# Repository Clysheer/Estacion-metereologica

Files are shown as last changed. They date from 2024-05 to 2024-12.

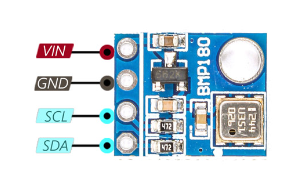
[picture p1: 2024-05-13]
PCB/Documentacion/Pin-out-BMP80.png

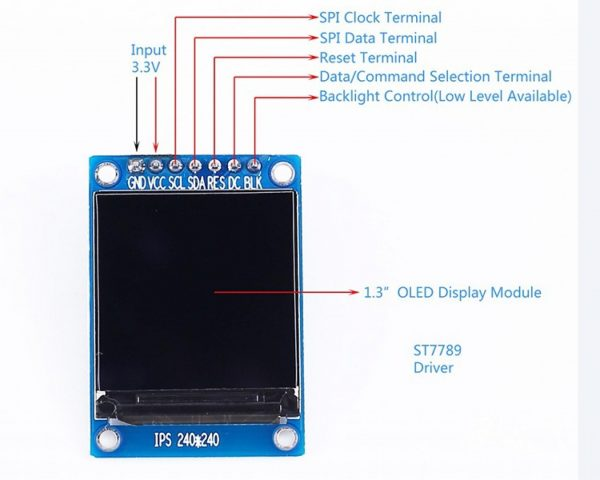
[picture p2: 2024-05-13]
PCB/Documentacion/Pin-ot-st7789.png

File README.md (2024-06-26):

# Estacion-metereologica
La  Estación  Meteorológica  es  un  dispositivo  que  tiene  la  capacidad  de  medir  la temperatura  ambiente,  humedad  y  presión  atmosférica  del  lugar  específico  en  el  que  se encuentre  el  dispositivo  y  también  puede  visualizar  la  temperatura  de  una  zona geográfica  predeterminada  (ej:  Lomas  de  Zamora).  Todo  esto  utilizando  la  pantalla ST7789 de 240*240 pixeles que al ser oled mostrará al usuario los datos extraídos de manera fácil y sencilla. Todo esto utilizando como cerebro al microcontrolador ESP32que  utilizando  su  conexión  Wifi  logre  interactuar  con  la  utilización  de  una  API,  la  cual recibirá  los  datos  de  la  zona  geográfica  y  los  mostrará  por  la  pantalla,  y  además, utilizando  los  sensores  de  Presión  Atmosférica  BPM  180  y  el    DHT11  de  temperatura  y humedad  calcule  la  temperatura  del  ambiente  y  la  presión  atmosférica.
En  definitiva,  es  un  dispositivo  compuesto  por  un  microcontrolador  ESP32,  una  pantalla oled  y  unos  sensores  de  temperatura,  humedad  y  presión  atmosférica.
Al  tamaño  de  la  pantalla  ser  relativamente  pequeña,  los  datos  extraídos  del  sensor DHT11  y  de  la  API  se  irán  mostrando  por  la  pantalla  ST7789  en  manera  de  turnos, cada  15  segundo  pasará  de  mostrar  la  temperatura  ambiente  a  mostrar  la  meteorología de manera ciclica, así el usuario puede recibir ambas informaciones sin la necesidad de la utilizacion de un boton.
Todo esto será alimentado sin la utilización de baterías, si no que será alimentado mediante un cargador de 240v con una salida de 5v (cargador de celular) que ira conectado a la placa del dispositivo.
El  proyecto  está  planteado  como  un  proyecto  de  inicio,  el  costo  económico  no  es  muy alto  y  sirve  como  inicio  a  la  utilización  del  microcontrolador  ESP32  y  su  conectividad wifi.



*Diagrama  en  bloques:*



*Materiales :*

1-Pantalla DISPLAY TFT ST7789  240*240

2-ESP  WROOM  32  DEVKIT  V1

3-DHT11 Sensor Temperatura 

4-Placa  PCB  Simple  Faz  10x10

5-Sensor Presion Atmosferica Bmp180

*Diseño 3D :*







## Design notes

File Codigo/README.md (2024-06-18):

Esta carpeta contiene todos los codigos utilizados para la creacion de la 
Estacion Meteorologica Soulka, Incluye el codigo base y los distintos codigos 
utilizados para los sensores dht11 y bmp180, pantalla st7789 y conexion Wifi.

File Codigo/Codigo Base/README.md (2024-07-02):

Codigo que se encuentra subido al esp32 utilizado por la Estacion Meteorologica

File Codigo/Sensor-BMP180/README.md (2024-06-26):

El sensor BMP180 es un sensor de presión atmosférica y temperatura barométrico de alta precisión fabricado por Bosch.                        puede proporcionar datos de temperatura, presión atmosférica y altitud.                                                                      
                                                                                                                                             El sensor de presión barométrica BMP180 está diseñado para leer la presión atmosférica y de esta forma estimar indirectamente la Altura sobre el nivel del mar. La presión atmosférica es la fuerza que ejerce el aire (atmósfera) sobre la superficie de la tierra. La presión atmosférica se debe al peso de la columna de aire sobre determinada área, es por esta razón que al medir la presión atmosférica en puntos con mayor altitud, el valor de la presión es menor por ser menor la cantidad de aire. La presión atmosférica también varía con el clima, principalmente con la temperatura, pues esta hace cambiar la densidad del aire, que se ve reflejado en un cambio en el peso y por consiguiente en un cambio de presión.                                                                                                                                                                                                                                                                                                                                                                                  Características Técnicas                                                                                                                                                                                                                                                             
Mediciones:                                                                                                                              
Presión atmosférica absoluta                                                                                                              
Temperatura ambiente.                                                                                                                                                                                                                                        
Precisión:                                                                                                                                
Presión:                                                                                                                                  
   Rango: 300 hPa a 1100 hPa.                                                                                                              
   Resolución: 0.01 hPa.                                                                                                                      
   Precisión: ±1 hPa.                                                                                                                      
Temperatura:  
  Rango: -40°C a +85°C.                                                                                                                      
  Resolución: 0.1°C.                                                                                                                                              
  Precisión: ±2°C.                                                                                                                                    
Voltaje de Operación: 1.8V a 3.6V (generalmente se usa con 3.3V o 5V).                                                                                  
Interfaz de Comunicación: Utiliza el protocolo I2C para la comunicación con microcontroladores.                                                                                                                                                                                                                                          
El sensor BMP180 tiene cuatro pines:

VCC: Alimentación (3.3V a 5V).                                                                                                                    
GND: Conexión a tierra.                                                                                                                                        
SCL: Línea de reloj del bus I2C.                                                                                                                          
SDA: Línea de datos del bus I2C.

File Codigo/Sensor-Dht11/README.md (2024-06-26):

El sensor DHT11 es un sensor utilizado para la medicion de temperatura y humedad,
a diferencia de otro sensores medidores de temperatura y humedad este presume de ser un sensor con una alta fiabilidad y estabilidad debido a su señal digital calibrada.

Caracteristicas Tecnicas:

Mediciones: Proporciona lecturas de temperatura y humedad relativa.                                                                          
Precisión:                                                                                                                                   
  Temperatura: ±2°C                                                                                                                            Humedad: ±5% RH                                                                                                                            Rango de Medición:                                                                                                                        
Temperatura: 0°C a 50°C
Humedad: 20% a 90% RH                                                                                                                       
Voltaje de Operación: 3.3V a 5V (generalmente se recomienda 5V para asegurar una operación estable)                                         
Interfaz de Comunicación: Utiliza un solo bus de datos para la lectura de los sensores de temperatura y humedad.                            
Tiempo de Respuesta: Lecturas de temperatura cada 2 segundos, y de humedad cada 2 segundos.

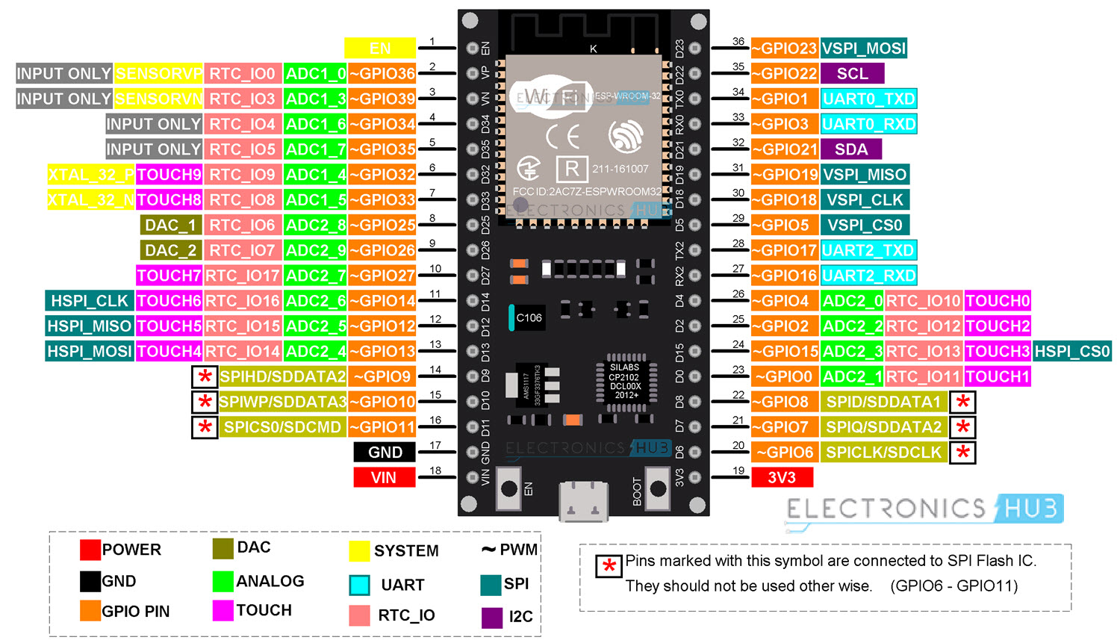
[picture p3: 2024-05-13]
PCB/Documentacion/Pin-out-Esp32.png

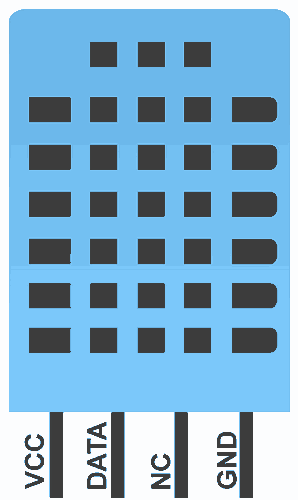
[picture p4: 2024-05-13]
PCB/Documentacion/Pin-out-DHT11.png

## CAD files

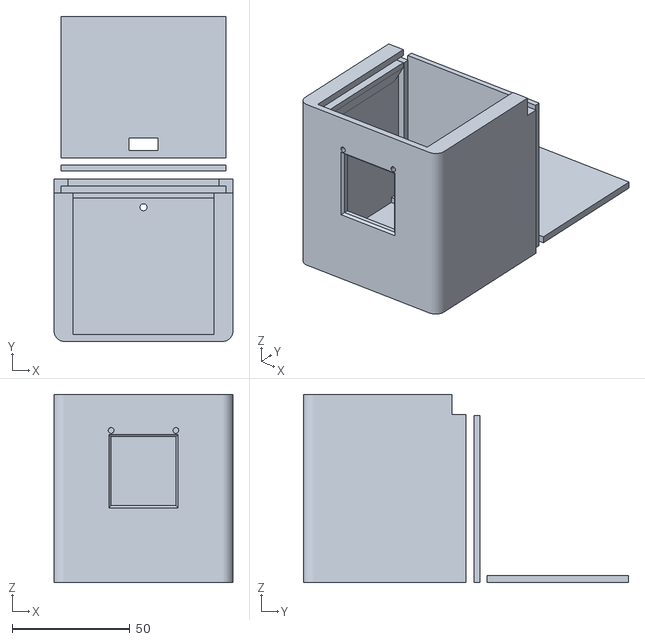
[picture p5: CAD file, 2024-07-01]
DISEÑO 3D/Estacion Meteorologica v6.stl
76.0 x 138.0 x 80.0

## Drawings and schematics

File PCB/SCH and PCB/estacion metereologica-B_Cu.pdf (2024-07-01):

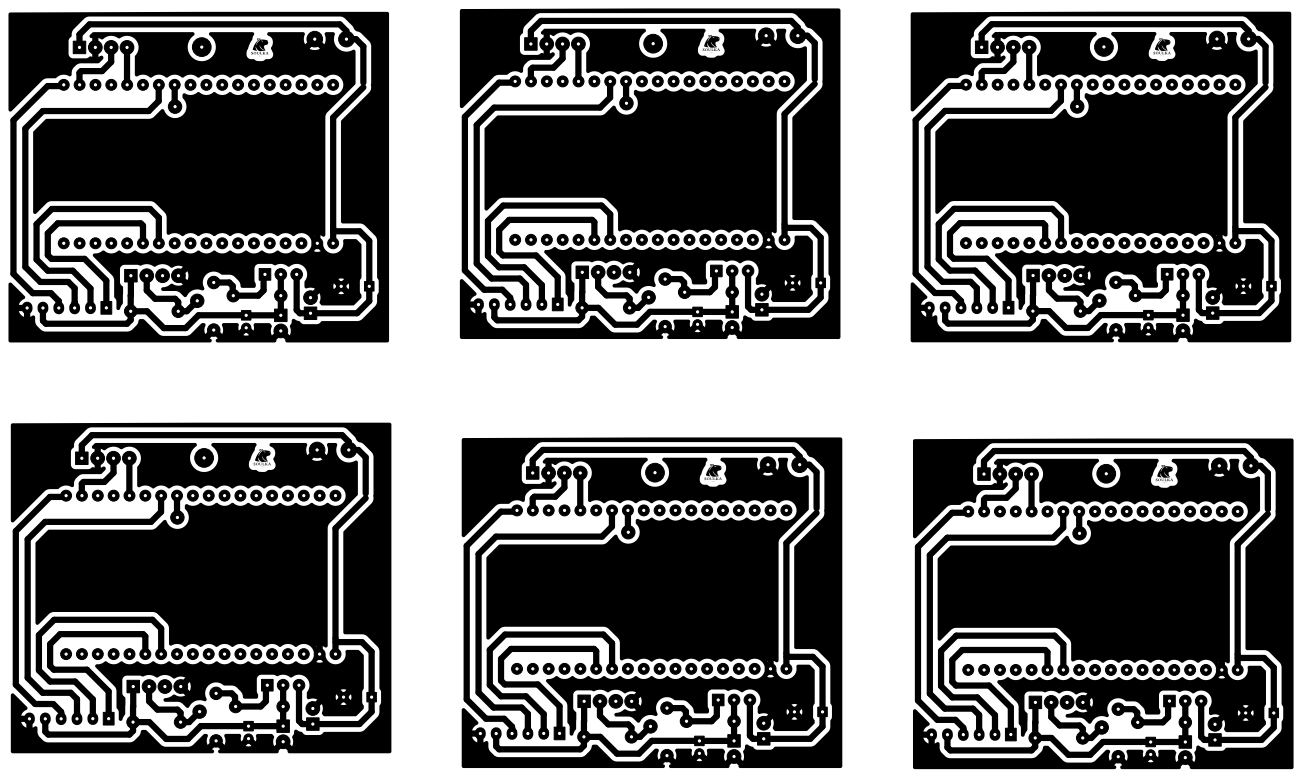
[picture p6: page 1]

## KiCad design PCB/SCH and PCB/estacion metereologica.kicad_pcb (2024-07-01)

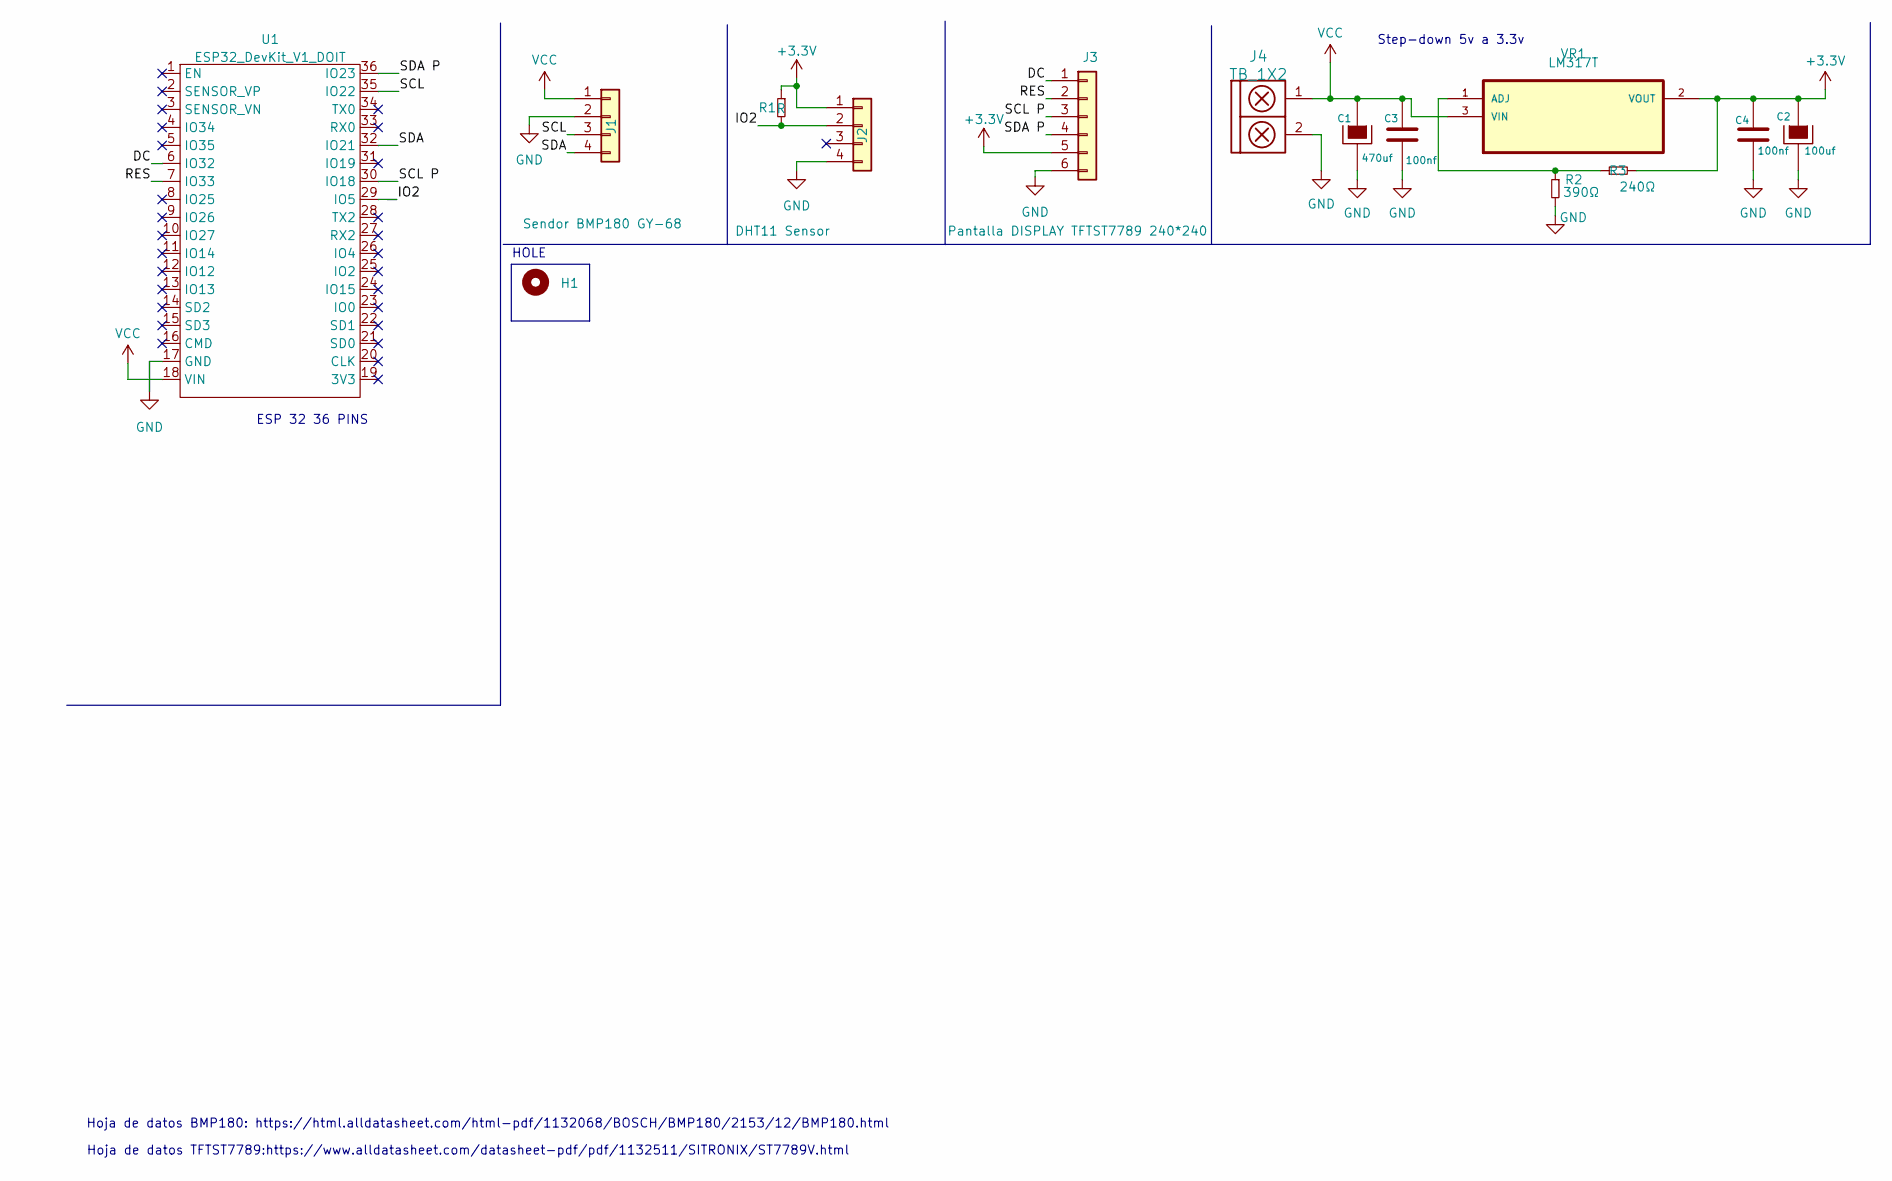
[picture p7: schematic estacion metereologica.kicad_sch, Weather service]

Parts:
C1: 470uf; CAP_ELEC_10X8mm
C2: 100uf; CAP_ELEC_5x11mm
C3, C4: 100nf; CP_Radial_Tantal_D4.5mm_P2.50mm
H1: Mounting_Hole; Tornillo_M3_8mm
J1: Sendor BMP180 GY-68; FanPinHeader_1x04_P2.54mm_Vertical
J2: DHT11 Sensor; FanPinHeader_1x04_P2.54mm_Vertical
J3: Pantalla DISPLAY TFTST7789 240*240; FanPinHeads_1x6_P2.54mm_Vertical
J4: TB_1X2; BORNERA2_AZUL
R1: R; RES0.3
R2: 390Ω; RES0.3
R3: 240Ω; RES0.3
U1: ESP32_DevKit_V1_DOIT; ESP32_DEVKIT_V1_DOIT
VR1: LM317T; TO254P1054X470X1955-3

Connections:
+3.3V: C2.1, C4.1, J2.1, J3.5, R1.1, R3.2, VR1.2 (VOUT)
/DC: J3.1, U1.6 (IO32)
/IO2: J2.2, R1.2, U1.29 (IO5)
/RES: J3.2, U1.7 (IO33)
/SCL: J1.3, U1.35 (IO22)
/SCL P: J3.3, U1.30 (IO18)
/SDA: J1.4, U1.32 (IO21)
/SDA P: J3.4, U1.36 (IO23)
GND: C1.2, C2.2, C3.2, C4.2, J1.2, J2.4, J3.6, J4.2, R2.2, U1.17 (GND)
unnamed: R2.1, R3.1, VR1.1 (ADJ)
VCC: C1.1, C3.1, J1.1, J4.1, U1.18 (VIN), VR1.3 (VIN)

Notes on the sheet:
Hoja de datos TFTST7789:https://www.alldatasheet.com/datasheet-pdf/pdf/1132511/SITRONIX/ST7789V.html
Step-down 5v a 3.3v
HOLE
Hoja de datos BMP180: https://html.alldatasheet.com/html-pdf/1132068/BOSCH/BMP180/2153/12/BMP180.html
ESP 32 36 PINS

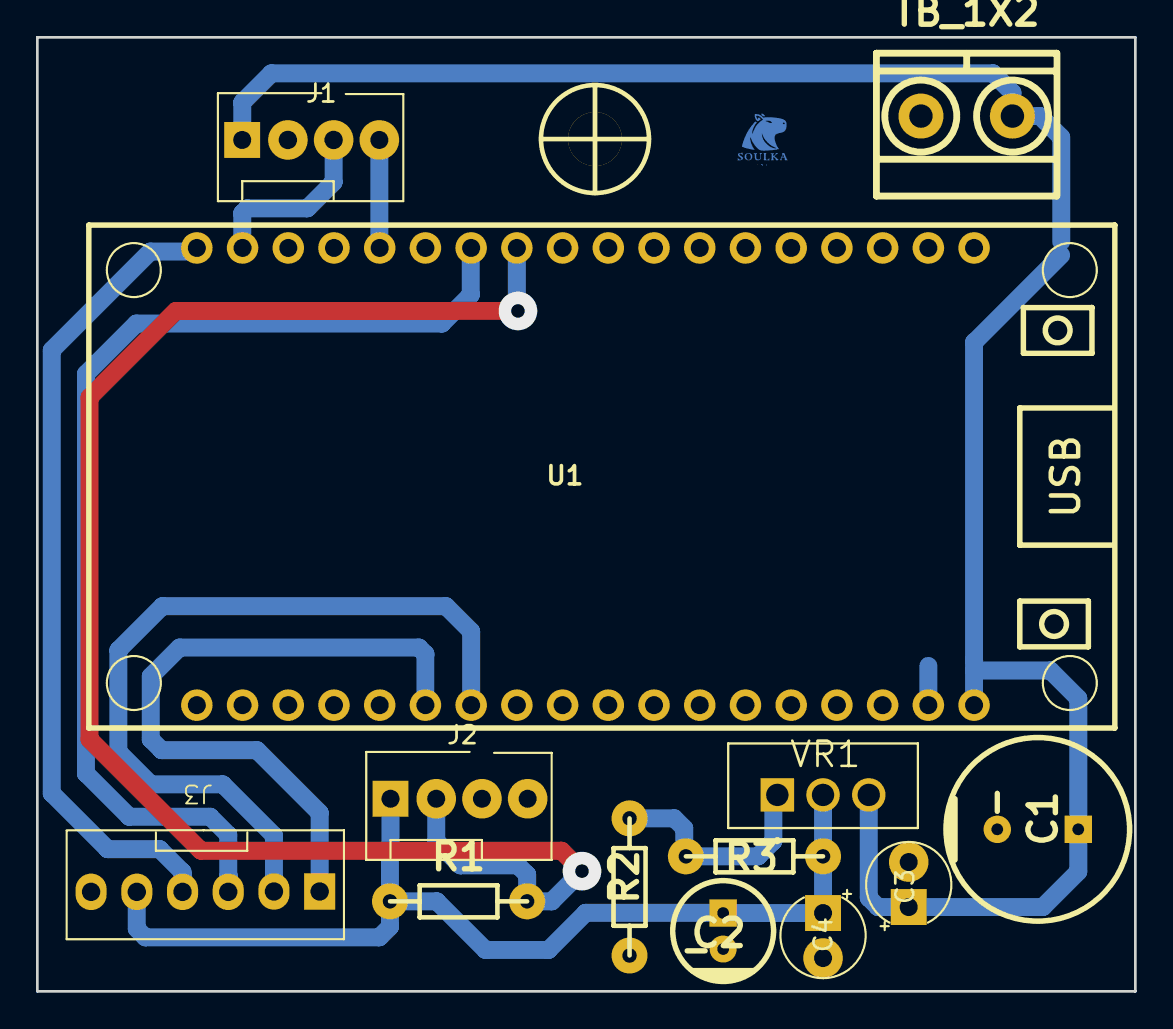
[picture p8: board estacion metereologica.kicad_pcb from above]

Board: 2 copper layers, 61.0 x 53.0 mm, 14 parts (0 on the bottom side), 11 nets.

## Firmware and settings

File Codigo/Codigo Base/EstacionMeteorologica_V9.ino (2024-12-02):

#include <WiFi.h>
#include <HTTPClient.h>
#include <ArduinoJson.h>
#include <TFT_eSPI.h>
#include <SPI.h>
#include <DHT.h>
#include <DHT_U.h>
#include <Adafruit_BMP085.h>

#define PIN_DHT 5
#define DHTTYPE DHT11
#define PRUEBA 1
DHT dht(PIN_DHT, DHTTYPE);
TFT_eSPI tft = TFT_eSPI();
Adafruit_BMP085 bmp;

//Redes wifi
//const char* ssid = "Taller_Electronica_5GHz";       
//const char* password = "robotica";
//const char* ssid = "Maestros";
//const char* password = "Maestros_2021";
const char* ssid = "Estudiantes";       
const char* password = "educar_2018";
//const char* ssid = "Vllamada";       
//const char* password = "Vllamada_2021";

String URL = "http://api.openweathermap.org/data/2.5/weather?"; // URL para la API
String ApiKey = "44d3a7d9ae8f99c1cdc98166cf3bb5f8";             //Clave de la URL

// Ubicacion de los parametros meteorologicos
String lat = "Temperley";               
String lon = "Argentina";


unsigned long tiempoAnterior = 0;  // Almacena el tiempo anterior
const long intervalo = 10000;  // Intervalo de 10 segundos (en milisegundos)

int estado = 0;  // Estado para alternar entre las dos frases

void setup() {
  Serial.begin(9600);
  WiFi.begin(ssid, password);
  tft.init();
  tft.fillScreen(TFT_BLACK);
  while (WiFi.status() != WL_CONNECTED) {
    delay(500);
    Serial.print(".");
    }
   Serial.println("");
   Serial.println("WiFi connected.");
   Serial.println("IP address: ");
   Serial.println(WiFi.localIP());
}
void Atmosferico(const float tempat, const float humat){
  if(PRUEBA){
    Serial.println(" Entro a Atmosferico");
  }
  
  tft.setTextColor(TFT_GREEN);
  tft.setCursor(47, 15);       
  tft.setTextFont(4);
  tft.print("TEMPERLEY");

   //Temperatura
  tft.setTextColor(TFT_RED);
  tft.setCursor(17, 55);
  tft.setTextFont(7);
  tft.print(tempat - 273.15);

    //Humedad
  tft.setTextColor(TFT_ORANGE);
  tft.setCursor(26, 150);
  tft.setTextFont(4);
  tft.print("Humedad: ");
  tft.print(humat);
  tft.print(" %");
}

void ImagenWifi(uint16_t color) {
  if (PRUEBA){
    Serial.println("icono wifi");
  }

  int x = tft.width() - 10;       // Coordenadas del símbolo WiFi
  int y = 0;

  
  tft.fillRect(x, y, 10, 10, TFT_BLACK);    // Borra el área del símbolo antes de dibujarlo 

  // Dibuja un símbolo de WiFi simple usando líneas y arcos dentro de un área de 10x10
  tft.drawPixel(x + 5, y + 8, color);                  // Punto central (señal)       
  tft.drawLine(x + 3, y + 6, x + 7, y + 6, color);     // Primera línea
  tft.drawLine(x + 2, y + 4, x + 8, y + 4, color);     // Segunda línea
  tft.drawLine(x + 1, y + 2, x + 9, y + 2, color);     // Tercera línea
  if (WiFi.status() == WL_CONNECTED) {
   // ImagenWifi(TFT_GREEN);
    Serial.println("Verde ambiente");
    } else {
   //  ImagenWifi(TFT_RED);
     Serial.println("Rojo ambiente");
    }
}

void TemAmbiente(){
  if (PRUEBA){
    Serial.println("Ambiente");
   }

  
  float tempdht;
  float humedad;
  float presion;
  tempdht = dht.readTemperature();
  humedad = dht.readHumidity();
  presion = bmp.readPressure() / 100.00;
  //Temperatura
  tft.setTextColor(TFT_RED);
  tft.setCursor(26, 55);
  tft.setTextFont(7);
  tft.print(tempdht);
  //Humedad
  tft.setTextColor(TFT_ORANGE);
  tft.setCursor(26, 150);
  tft.setTextFont(4);
  tft.print("Hum: ");
  tft.print(humedad);
  tft.println("%");
  //Presion Atmosferica
  tft.setTextColor(TFT_VIOLET);
  tft.setCursor(26, 180);
  tft.setTextFont(4);
 tft.print("Pa: ");
 tft.print(presion, 2);
 tft.println("hPa");
  
}
void Redes(){
  HTTPClient http;
    // Establecer la URL final de la solicitud HTTP con la ubicación y la información de la clave de API
  http.begin(URL + "q=" + lat + "," + lon + "&appid=" + ApiKey);
  // iniciar la conexión y enviar la solicitud HTTP
  int httpCode = http.GET();
  // httpCode será negativo en caso de error
    if (httpCode > 0) {
     // Leer datos como una cadena JSON
      String JSON_Data = http.getString();
      // Recuperar información sobre el tiempo desde el formato JSON
      DynamicJsonDocument doc(2048);
      deserializeJson(doc, JSON_Data);
      JsonObject obj = doc.as<JsonObject>();

      const float tempat = obj["main"]["temp"].as<float>();       // Mostrar la información meteorológica
      const float humat = obj["main"]["humidity"].as<float>();
      Atmosferico(tempat, humat);
      } else {
        http.end();
     }
  delay(10000);
}
void loop() {
  unsigned long tiempoActual = millis();  // Obtiene el tiempo actual

  // Verifica si han pasado 10 segundos (10000 milisegundos)
  if (tiempoActual - tiempoAnterior >= intervalo) {
    // Guarda el tiempo actual como "tiempoAnterior"
    tiempoAnterior = tiempoActual;

    // Cambia entre las dos frases
    if (estado == 0) {
      tft.fillScreen(TFT_BLACK);
      delay(200);
      TemAmbiente();
      estado = 1;
    } else {
      tft.fillScreen(TFT_BLACK);
      delay(200);
      Redes();
      estado = 0;
    }
  }

}

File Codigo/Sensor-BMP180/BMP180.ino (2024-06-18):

#include <Adafruit_BMP085.h>

Adafruit_BMP085 bmp;

float temperaturabmp;
float presionatmos;

void setup() {
  Serial.begin(9600);
  bmp.begin();
}

void loop() {
  temperaturabmp = bmp.readTemperature();
  presionatmos = bmp.readPressure();
  Serial.print("Temperatura = ");
  Serial.print(temperaturabmp);
  Serial.println(" *C");

  Serial.print("Presion At ");
  Serial.print(presionatmos);
  Serial.println(" Pa");
  delay(500);
}

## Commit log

2024-04-29 Code Esp32 + API
    In this code the ESP32 microcontroller is connected with an API. This API is the weather service, their website is https://openweathermap.org. In this API you can obtain climate data from the geograp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
2024-04-29 Rename estacionm-serialprint.ino to wheather sevice-serial-print.ino
2024-05-13 PCB
    En esta carpeta se encuentran el esquemático y PCB del proyecto, además de la documentación de cada elemento utilizado.
    In this folder you will find the schematic and PCB of the project, as well as the documentation for each element used.
2024-05-13 PCB
    En esta carpeta se encuentra el esquemático y PCB del proyecto,además de su documentación
    [estacion metereologica.kicad_pcb, estacion metereologica.kicad_sch]
2024-07-01 add pcb
    [estacion metereologica.kicad_pcb, estacion metereologica.kicad_sch]
2024-07-01 Add Diseño 3D
    [Estacion Meteorologica v6.stl]
2024-07-03 archivos sin carpeta de la libreria
